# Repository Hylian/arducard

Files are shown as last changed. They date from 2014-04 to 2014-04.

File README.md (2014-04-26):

arducard
========

An open-source Arduino derivative e-paper dev device.

Features
-----

* ATmega32U4 (Same as the Arduino Leonardo)
* USB transceiver
* DS1343 Real-Time Clock
* 128KB FRAM
* LiR2016 Coin-cell Li-Ion battery
* Battery charging over USB
* 2.7" e-Paper display
* 5 edge-mounted interrupt-triggered tactile buttons

Dimensions
----------

80 mm x 45 mm x 5 mm

Applications
------------

* Google Auth Time-OTP 
* Store barcodes for rewards cards, etc.
* Store QR codes
* USB text terminal for Raspberry Pi
* ...

Interested?
-----------

Tweet me at [@inwardshed](https://twitter.com/inwardshed) or e-mail at [edshin95@gmail.com](mailto:edshin95@gmail.com) if you're interested in assembling a PCB/contributing.

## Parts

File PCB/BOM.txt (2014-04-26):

Partlist

Exported from arducard.sch at 4/12/2014 8:20:19 PM

EAGLE Version 6.5.0 Copyright (c) 1988-2013 CadSoft

Assembly variant: 

Part     Value           Device             Package             Library                 Sheet

B2       LIR2016         LIR2016            BK-5067             arducard-coincell       1
C1       100n            C-EUC0603          C0603-ROUND         SmartPrj                1
C2       100n            C-EUC0603          C0603-ROUND         SmartPrj                1
C3       22p             C-EUC0603          C0603-ROUND         SmartPrj                1
C4       22p             C-EUC0603          C0603-ROUND         SmartPrj                1
C5       1uF             C-EUC0603          C0603-ROUND         SmartPrj                1
C6       1uF             C-EUC0603          C0603-ROUND         SmartPrj                1
C7       100nF           C-EUC0603          C0603-ROUND         SmartPrj                1
C8       10u             C-EUC0603          C0603-ROUND         SmartPrj                1
C9       100n            C-EUC0603          C0603-ROUND         SmartPrj                1
C10      4.7 uF          C-EUC0603          C0603-ROUND         SmartPrj                1
C11      10 uF           C-EUC0603          C0603-ROUND         SmartPrj                1
C12      100pF           C-EUC0603          C0603-ROUND         SmartPrj                1
C13      22 pF           C-EUC0603          C0603-ROUND         SmartPrj                1
C14      1uF             C-EUC0603          C0603-ROUND         SmartPrj                1
C15      2.2uF/10V       C-EUC0603          C0603-ROUND         SmartPrj                1
C16      2.2uF/16V       C-EUC0603          C0603-ROUND         SmartPrj                1
C17      2.2uF/16V       C-EUC0603          C0603-ROUND         SmartPrj                1
C18      2.2uF/25V       C-EUC0603          C0603-ROUND         SmartPrj                1
C19      2.2uF/16V       C-EUC0603          C0603-ROUND         SmartPrj                1
C20      2.2uF/25V       C-EUC0603          C0603-ROUND         SmartPrj                1
C21      2.2uF/25V       C-EUC0603          C0603-ROUND         SmartPrj                1
C22      2.2uF/16V       C-EUC0603          C0603-ROUND         SmartPrj                1
C23      2.2uF/16V       C-EUC0603          C0603-ROUND         SmartPrj                1
C24      2.2uF/16V       C-EUC0603          C0603-ROUND         SmartPrj                1
C25      2.2uF/16V       C-EUC0603          C0603-ROUND         SmartPrj                1
C26      1uF/10V         C-EUC0603          C0603-ROUND         SmartPrj                1
C27      2.2uF/25V       C-EUC0603          C0603-ROUND         SmartPrj                1
C28      2.2uF/25V       C-EUC0603          C0603-ROUND         SmartPrj                1
C29      2.2uF/16V       C-EUC0603          C0603-ROUND         SmartPrj                1
C30      2.2uF/16V       C-EUC0603          C0603-ROUND         SmartPrj                1
C31      100nF           C-EUC0603          C0603-ROUND         SmartPrj                1
C32      0.1uF/16V       C-EUC0603          C0603-ROUND         SmartPrj                1
C33      2.2uF/16V       C-EUC0603          C0603-ROUND         SmartPrj                1
D1       BAS40           BAS40              SOT23               diode                   1
D2       BAT54S          BAT54S             SOT23               diode                   1
ICSP     ICSP            PINHD-2X3          2X03                SmartPrj                1
J1       USB MICRO B     MYCON2_USB-MINI-B  CON2_USB_MICRO_B_AT SmartPrj                1
J3       051296-4094     051296-4094        051296-4094         arducard-fpc            1
L2       2.2 uH          INDUCTOR30OHM,1.8A 0603                SparkFun-Passives       1
Q1       BSS84           BSS84              SOT23               transistor-small-signal 1
Q2       BC817-16LT1SMD  BC817-16LT1SMD     SOT23-BEC           transistor-npn          1
Q3       DMG2301U-7      DMG2301U-7         SOT23               transistor-fet          1
Q4       2N7002          2N7002             SOT-23              AWJLEagleLib            1
Q5       BSS84           BSS84              SOT23               transistor-small-signal 1
Q6       2N7002          2N7002             SOT-23              AWJLEagleLib            1
Q7       2N7002          2N7002             SOT-23              AWJLEagleLib            1
Q8       2N7002          2N7002             SOT-23              AWJLEagleLib            1
Q9       BSS84           BSS84              SOT23               transistor-small-signal 1
Q10      DMG2301U-7      DMG2301U-7         SOT23               transistor-fet          1
R1       1M              R-EU_R0603         R0603-ROUND         SmartPrj                1
R2       10k             R-EU_R0603         R0603-ROUND         SmartPrj                1
R3       22R             R-EU_R0603         R0603-ROUND         SmartPrj                1
R4       22R             R-EU_R0603         R0603-ROUND         SmartPrj                1
R5       2k              R-EU_R0603         R0603-ROUND         SmartPrj                1
R6       100k            R-EU_R0603         R0603-ROUND         SmartPrj                1
R7       39k             R-EU_R0603         R0603-ROUND         SmartPrj                1
R8       10k             R-EU_R0603         R0603-ROUND         SmartPrj                1
R9       10k             R-EU_R0603         R0603-ROUND         SmartPrj                1
R10      10k             R-EU_R0603         R0603-ROUND         SmartPrj                1
R11      10k             R-EU_R0603         R0603-ROUND         SmartPrj                1
R12      10k             R-EU_R0603         R0603-ROUND         SmartPrj                1
R13      10k             R-EU_R0603         R0603-ROUND         SmartPrj                1
R14      150             R-EU_R0603         R0603-ROUND         SmartPrj                1
R15      150             R-EU_R0603         R0603-ROUND         SmartPrj                1
R16      150             R-EU_R0603         R0603-ROUND         SmartPrj                1
R17      150             R-EU_R0603         R0603-ROUND         SmartPrj                1
R18      150             R-EU_R0603         R0603-ROUND         SmartPrj                1
R19      10k             R-EU_R0603         R0603-ROUND         SmartPrj                1
R20      18.2k           R-EU_R0603         R0603-ROUND         SmartPrj                1
R23      2k              R-EU_R0603         R0603-ROUND         SmartPrj                1
R24      100k            R-EU_R0603         R0603-ROUND         SmartPrj                1
R25      100k            R-EU_R0603         R0603-ROUND         SmartPrj                1
R26      100k            R-EU_R0603         R0603-ROUND         SmartPrj                1
R27      33k             R-EU_R0603         R0603-ROUND         SmartPrj                1
R28      10k             R-EU_R0603         R0603-ROUND         SmartPrj                1
SW0      EVQ-PUA         EVQ-PUA            SMD-TACT-SWITCH     arducard-switch         1
SW1      EVQ-PUA         EVQ-PUA            SMD-TACT-SWITCH     arducard-switch         1
SW2      EVQ-PUA         EVQ-PUA            SMD-TACT-SWITCH     arducard-switch         1
SW3      EVQ-PUA         EVQ-PUA            SMD-TACT-SWITCH     arducard-switch         1
SW4      EVQ-PUA         EVQ-PUA            SMD-TACT-SWITCH     arducard-switch         1
U1       ATMEGA32U4-XUAU ATMEGA32U4-XUAU    TQFP44-PAD          SmartPrj                1
U2                       MIC5219XX          SOT23-5             v-reg-micrel            1
U3       MB85RS128B-FRAM MB85RS128B-FRAM    SO-08               arducard-fram           1
U4       DS1343          DS1343             TSSOP20             arducard-rtc            1
U5       XC6802A42XMR-G  XC6802A42XMR-G     SOT23-5L            arducard-xc6802         1
Y1       8MHz KX-7       CRYSTAL-3.2-2.5    CRYSTAL-3.2-2.5     SmartPrj                1
Y2       32.768 kHz      SSP-T7-F           SSP-T7-F            arducard-rtc            1
Z1       CG0603MLC-05E   VARISTORCN0603     CT/CN0603           varistor                1
Z2       CG0603MLC-05E   VARISTORCN0603     CT/CN0603           varistor                1

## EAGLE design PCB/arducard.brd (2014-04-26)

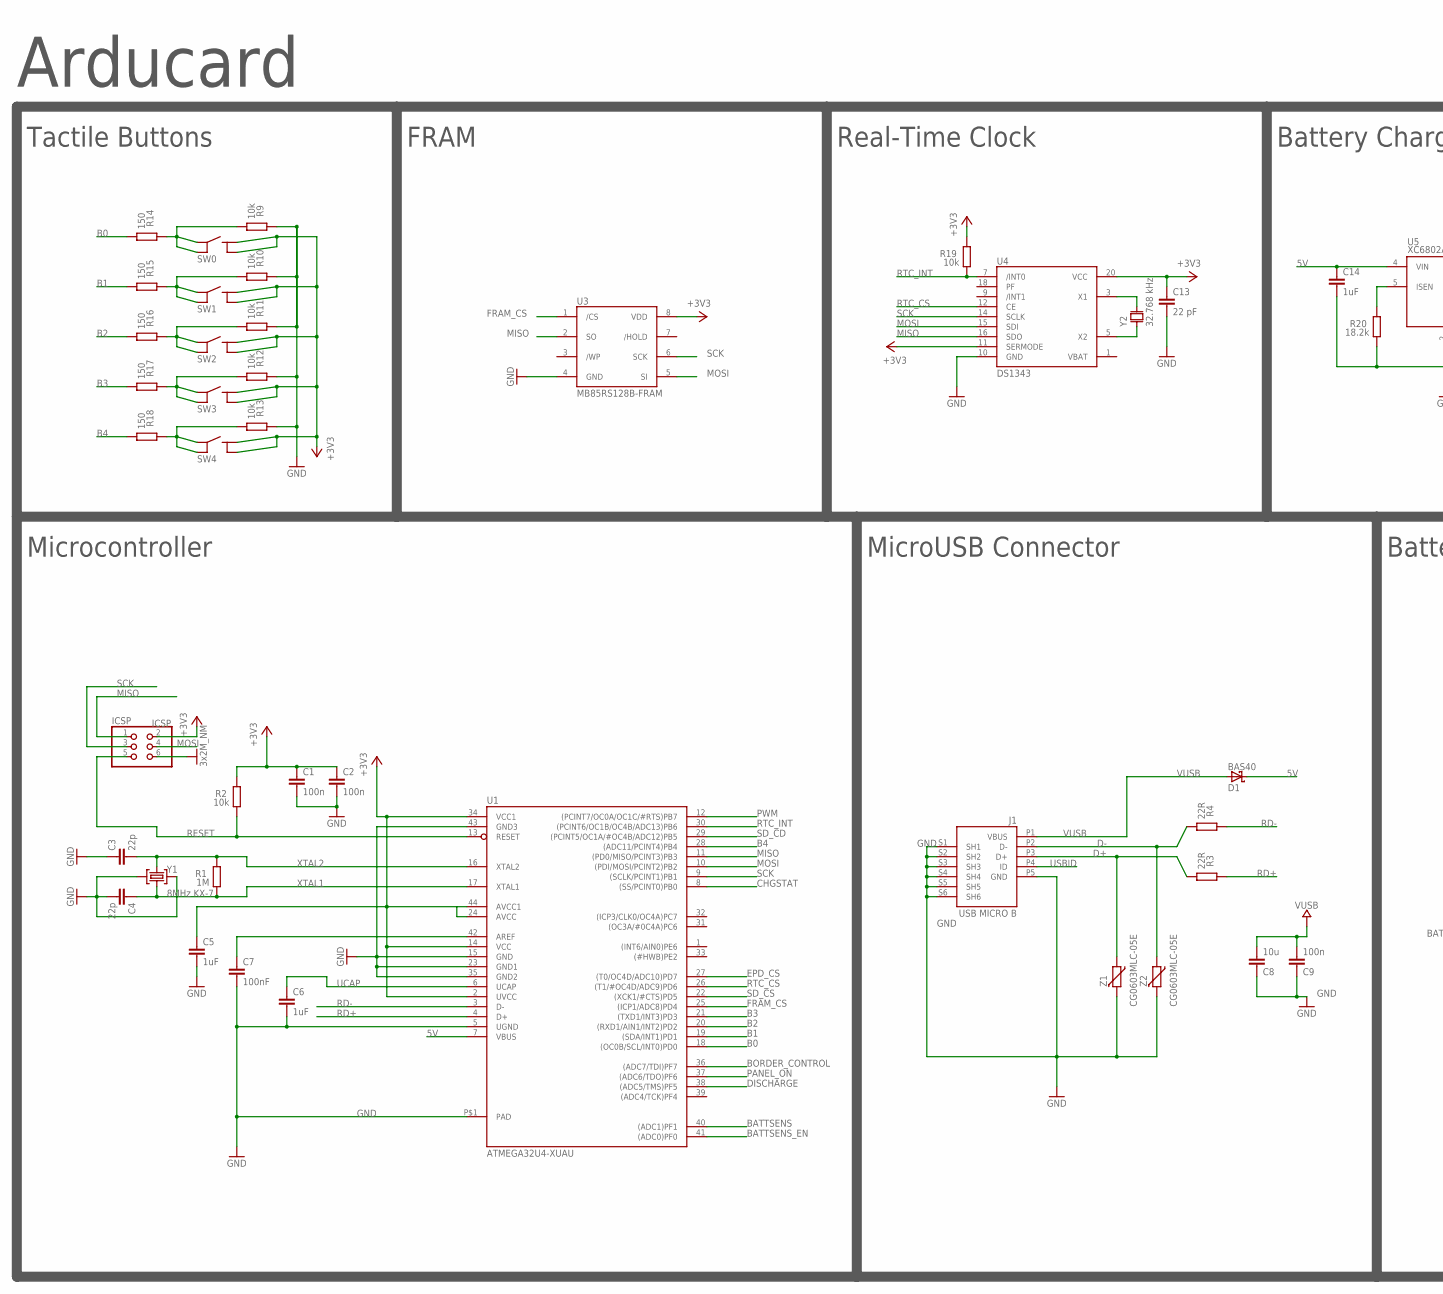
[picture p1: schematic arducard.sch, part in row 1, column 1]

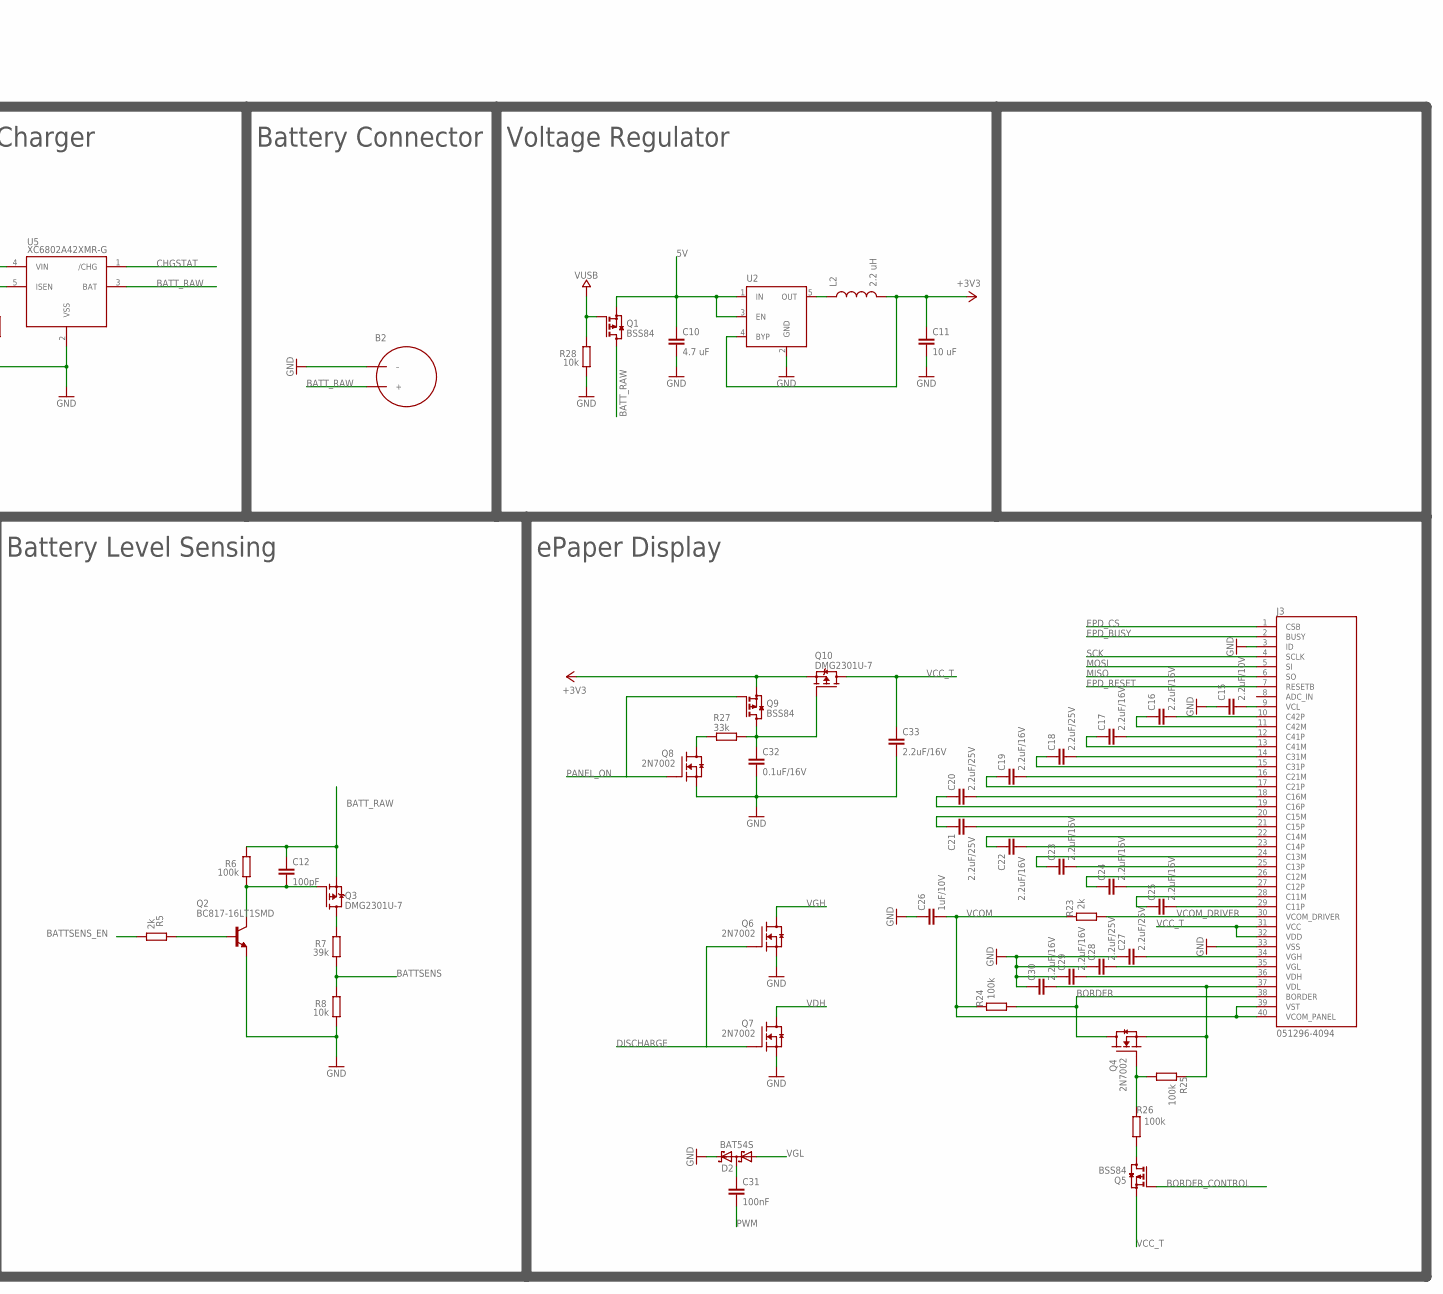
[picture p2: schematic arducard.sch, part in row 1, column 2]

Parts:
B2: LIR2016; BK-5067
C1, C2, C9: 100n; C0603-ROUND
C3, C4: 22p; C0603-ROUND
C5, C6, C14: 1uF; C0603-ROUND
C7, C31: 100nF; C0603-ROUND
C8: 10u; C0603-ROUND
C10: 4.7 uF; C0603-ROUND
C11: 10 uF; C0603-ROUND
C12: 100pF; C0603-ROUND
C13: 22 pF; C0603-ROUND
C15: 2.2uF/10V; C0603-ROUND
C16, C17, C19, C22, C23, C24, C25, C29, C30, C33: 2.2uF/16V; C0603-ROUND
C18, C20, C21, C27, C28: 2.2uF/25V; C0603-ROUND
C26: 1uF/10V; C0603-ROUND
C32: 0.1uF/16V; C0603-ROUND
D1: BAS40; SOT23
D2: BAT54S; SOT23
ICSP: ICSP; 2X03
J1: USB MICRO B; CON2_USB_MICRO_B_AT
J3: 051296-4094
L2: 2.2 uH; 0603
Q1, Q5, Q9: BSS84; SOT23
Q2: BC817-16LT1SMD; SOT23-BEC
Q3, Q10: DMG2301U-7; SOT23
Q4, Q6, Q7, Q8: 2N7002; SOT-23
R1: 1M; R0603-ROUND
R2, R8, R9, R10, R11, R12, R13, R19, R28: 10k; R0603-ROUND
R3, R4: 22R; R0603-ROUND
R5, R23: 2k; R0603-ROUND
R6, R24, R25, R26: 100k; R0603-ROUND
R7: 39k; R0603-ROUND
R14, R15, R16, R17, R18: 150; R0603-ROUND
R20: 18.2k; R0603-ROUND
R27: 33k; R0603-ROUND
SW0, SW1, SW2, SW3, SW4: EVQ-PUA; SMD-TACT-SWITCH
U1: ATMEGA32U4-XUAU; TQFP44-PAD
U2: MIC5219XX; SOT23-5
U3: MB85RS128B-FRAM; SO-08
U4: DS1343; TSSOP20
U5: XC6802A42XMR-G; SOT23-5L
Y1: 8MHz KX-7; CRYSTAL-3.2-2.5
Y2: 32.768 kHz; SSP-T7-F
Z1, Z2: CG0603MLC-05E; CT/CN0603

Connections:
5V: C10.1, C14.1, D1.3 (C), Q1.2 (S), U1.7 (VBUS), U2.1 (IN), U2.3 (EN), U5.4 (VIN)
+3V3: C1.1, C2.1, C5.1, C11.1, C13.1, ICSP.2, L2.2, Q9.2 (S), Q10.2 (S), R2.2, R19.2, SW0.2, SW0.4, SW1.2, SW1.4, SW2.2, SW2.4, SW3.2, SW3.4, SW4.2, SW4.4, U1.2 (UVCC), U1.14 (VCC), U1.24 (AVCC), U1.34 (VCC1), U1.44 (AVCC1), U2.4 (BYP), U3.8 (VDD), U4.11 (SERMODE), U4.20 (VCC)
B0: R14.1, U1.18 ((OC0B/SCL/INT0)PD0)
B1: R15.1, U1.19 ((SDA/INT1)PD1)
B2: R16.1, U1.20 ((RXD1/AIN1/INT2)PD2)
B3: R17.1, U1.21 ((TXD1/INT3)PD3)
B4: R18.1, U1.28 ((ADC11/PCINT4)PB4)
BATTSENS: R7.1, R8.2, U1.40 ((ADC1)PF1)
BATTSENS_EN: R5.1, U1.41 ((ADC0)PF0)
BATT_RAW: B2.POS1 (+), B2.POS2 (+), C12.1, Q1.3 (D), Q3.2 (S), R6.2, U5.3 (BAT)
BORDER: J3.38 (BORDER), Q4.3 (D), R24.2
BORDER_CONTROL: Q5.1 (G), U1.36 ((ADC7/TDI)PF7)
CHGSTAT: U1.8 ((SS/PCINT0)PB0), U5.1 (/CHG)
D+: J1.P3 (D+), R3.1, Z1.1
D-: J1.P2 (D-), R4.1, Z2.1
DISCHARGE: Q6.1 (G), Q7.1 (G), U1.38 ((ADC5/TMS)PF5)
EPD_BUSY: J3.2 (BUSY)
EPD_CS: J3.1 (CSB), U1.27 ((T0/OC4D/ADC10)PD7)
EPD_RESET: J3.7 (RESETB)
FRAM_CS: U1.25 ((ICP1/ADC8)PD4), U3.1 (/CS)
GND: B2.NEG (–), C1.2, C2.2, C3.1, C4.2, C5.2, C6.2, C7.2, C8.1, C9.1, C10.2, C11.2, C13.2, C14.2, C15.1, C26.1, C27.1, C28.1, C29.1, C30.1, C32.2, C33.2, D2.2 (C2), ICSP.6, J1.P5 (GND), J1.S1 (SH1), J1.S2 (SH2), J1.S3 (SH3), J1.S4 (SH4), J1.S5 (SH5), J1.S6 (SH6), J3.3 (ID), J3.33 (VSS), Q2.E, Q6.2 (S), Q7.2 (S), Q8.2 (S), R8.1, R9.2, R10.2, R11.2, R12.2, R13.2, R20.1, R28.1, U1.5 (UGND), U1.15 (GND), U1.23 (GND1), U1.35 (GND2), U1.43 (GND3), U1.P$1 (PAD), U2.2 (GND), U3.4 (GND), U4.10 (GND), U5.2 (VSS), Y1.2 (GND), Y1.4 (GND), Z1.2, Z2.2
MISO: ICSP.1, J3.6 (SO), U1.11 ((PD0/MISO/PCINT3)PB3), U3.2 (SO), U4.16 (SDO)
MOSI: ICSP.4, J3.5 (SI), U1.10 ((PDI/MOSI/PCINT2)PB2), U3.5 (SI), U4.15 (SDI)
unnamed: C15.2, J3.9 (VCL)
unnamed: R10.1, R15.2, SW1.1, SW1.3
unnamed: R9.1, R14.2, SW0.1, SW0.3
unnamed: U4.3 (X1), Y2.P$4
unnamed: R11.1, R16.2, SW2.1, SW2.3
unnamed: R12.1, R17.2, SW3.1, SW3.3
unnamed: L2.1, U2.5 (OUT)
unnamed: R13.1, R18.2, SW4.1, SW4.3
unnamed: C7.1, U1.42 (AREF)
unnamed: C12.2, Q2.C, Q3.1 (G), R6.1
unnamed: C16.2, J3.10 (C42P)
unnamed: Q3.3 (D), R7.2
unnamed: C16.1, J3.11 (C42M)
unnamed: C17.2, J3.12 (C41P)
unnamed: C17.1, J3.13 (C41M)
unnamed: U4.5 (X2), Y2.P$1
unnamed: C18.2, J3.14 (C31M)
unnamed: C18.1, J3.15 (C31P)
unnamed: C19.2, J3.16 (C21M)
unnamed: C19.1, J3.17 (C21P)
unnamed: C20.2, J3.18 (C16M)
unnamed: C20.1, J3.19 (C16P)
unnamed: C21.1, J3.20 (C15M)
unnamed: C21.2, J3.21 (C15P)
unnamed: C22.2, J3.23 (C14P)
unnamed: C22.1, J3.22 (C14M)
unnamed: C23.2, J3.25 (C13P)
unnamed: C23.1, J3.24 (C13M)
unnamed: C24.2, J3.27 (C12P)
unnamed: C24.1, J3.26 (C12M)
unnamed: C25.2, J3.29 (C11P)
unnamed: C25.1, J3.28 (C11M)
unnamed: Q8.3 (D), R27.1
unnamed: R20.2, U5.5 (ISEN)
unnamed: Q5.3 (D), R26.2
unnamed: Q4.1 (G), R25.2, R26.1
unnamed: C31.1, D2.3 (C1A2)
unnamed: C32.1, Q9.3 (D), Q10.1 (G), R27.2
PANEL_ON: Q8.1 (G), Q9.1 (G), U1.37 ((ADC6/TDO)PF6)
PWM: C31.2, U1.12 ((PCINT7/OC0A/OC1C/#RTS)PB7)
Q2: Q2.B, R5.2
RD+: R3.2, U1.4 (D+)
RD-: R4.2, U1.3 (D-)
RESET: ICSP.5, R2.1, U1.13 (RESET)
RTC_CS: U1.26 ((T1/#OC4D/ADC9)PD6), U4.12 (CE)
RTC_INT: R19.1, U1.30 ((PCINT6/OC1B/OC4B/ADC13)PB6), U4.7 (/INT0)
SCK: ICSP.3, J3.4 (SCLK), U1.9 ((SCLK/PCINT1)PB1), U3.6 (SCK), U4.14 (SCLK)
SD_CD: U1.29 ((PCINT5/OC1A/#OC4B/ADC12)PB5)
SD_CS: U1.22 ((XCK1/#CTS)PD5)
UCAP: C6.1, U1.6 (UCAP)
USBID: J1.P4 (ID)
VCC_T: C33.1, J3.31 (VCC), J3.32 (VDD), Q5.2 (S), Q10.3 (D)
VCOM: C26.2, J3.39 (VST), J3.40 (VCOM_PANEL), R23.1, R24.1
VCOM_DRIVER: J3.30 (VCOM_DRIVER), R23.2
VDH: C29.2, J3.36 (VDH), Q7.3 (D)
VDL: C30.2, J3.37 (VDL), Q4.2 (S), R25.1
VGH: C27.2, J3.34 (VGH), Q6.3 (D)
VGL: C28.2, D2.1 (A1), J3.35 (VGL)
VUSB: C8.2, C9.2, D1.1 (A), J1.P1 (VBUS), Q1.1 (G), R28.2
XTAL1: C4.1, R1.1, U1.17 (XTAL1), Y1.1 (C1)
XTAL2: C3.2, R1.2, U1.16 (XTAL2), Y1.3 (C2)

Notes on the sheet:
Voltage Regulator
Battery Connector
Battery Charger
Real-Time Clock
FRAM
Tactile Buttons
Microcontroller
MicroUSB Connector
Battery Level Sensing
ePaper Display
Arducard

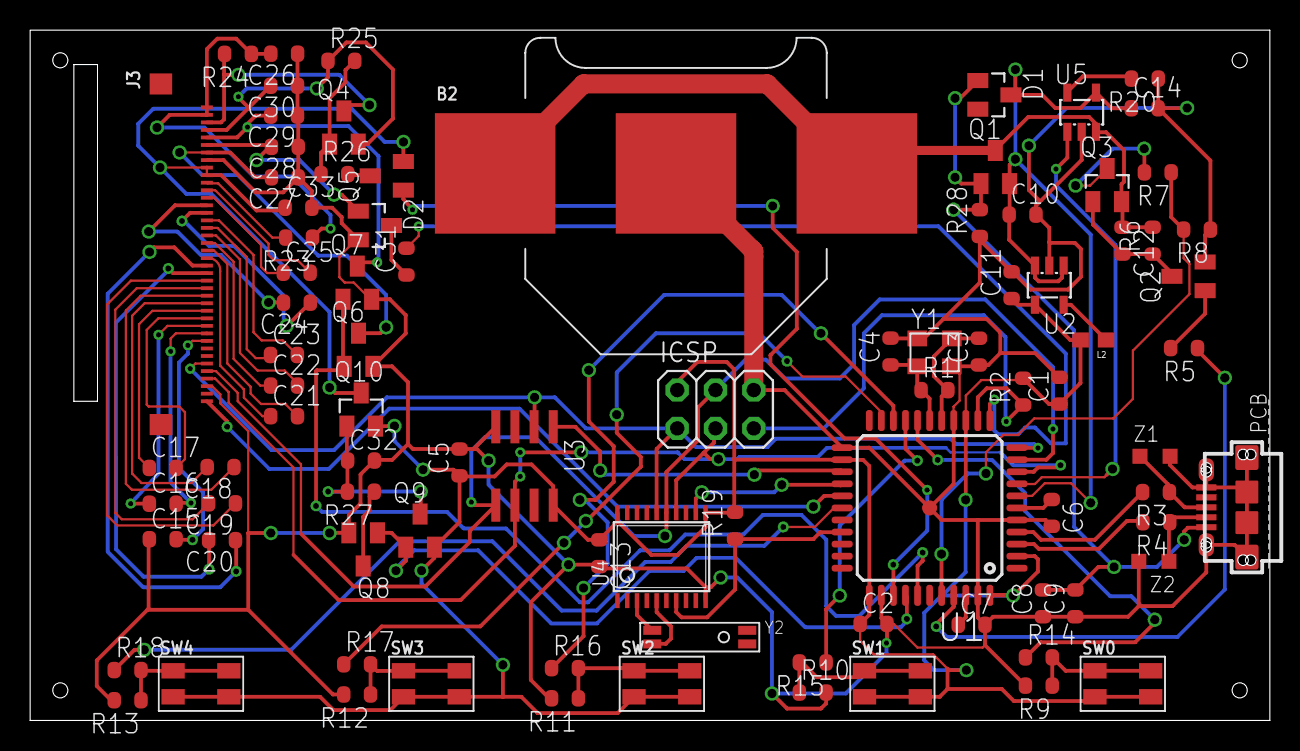
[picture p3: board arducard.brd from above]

Board: 2 copper layers, 82.3 x 45.8 mm, 90 parts (0 on the bottom side), 79 nets.

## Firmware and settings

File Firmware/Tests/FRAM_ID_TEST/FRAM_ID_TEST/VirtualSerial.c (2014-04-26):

/*
             LUFA Library
     Copyright (C) Dean Camera, 2014.

  dean [at] fourwalledcubicle [dot] com
           www.lufa-lib.org
*/

/*
  Copyright 2014  Dean Camera (dean [at] fourwalledcubicle [dot] com)

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
  The author disclaims all warranties with regard to this
  software, including all implied warranties of merchantability
  and fitness.  In no event shall the author be liable for any
  special, indirect or consequential damages or any damages
  whatsoever resulting from loss of use, data or profits, whether
  in an action of contract, negligence or other tortious action,
  arising out of or in connection with the use or performance of
  this software.
*/

/** \file
 *
 *  Main source file for the VirtualSerial demo. This file contains the main tasks of
 *  the demo and is responsible for the initial application hardware configuration.
 */

#include "VirtualSerial.h"
#include <avr/io.h>
#include <util/delay.h>


#define SELECT_FRAM PORTD &= ~(0x08)
#define DESELECT_FRAM PORTD |= 0x08

/** LUFA CDC Class driver interface configuration and state information. This structure is
 *  passed to all CDC Class driver functions, so that multiple instances of the same class
 *  within a device can be differentiated from one another.
 */
USB_ClassInfo_CDC_Device_t VirtualSerial_CDC_Interface =
	{
		.Config =
			{
				.ControlInterfaceNumber   = INTERFACE_ID_CDC_CCI,
				.DataINEndpoint           =
					{
						.Address          = CDC_TX_EPADDR,
						.Size             = CDC_TXRX_EPSIZE,
						.Banks            = 1,
					},
				.DataOUTEndpoint =
					{
						.Address          = CDC_RX_EPADDR,
						.Size             = CDC_TXRX_EPSIZE,
						.Banks            = 1,
					},
				.NotificationEndpoint =
					{
						.Address          = CDC_NOTIFICATION_EPADDR,
						.Size             = CDC_NOTIFICATION_EPSIZE,
						.Banks            = 1,
					},
			},
	};

/** Standard file stream for the CDC interface when set up, so that the virtual CDC COM port can be
 *  used like any regular character stream in the C APIs.
 */
static FILE USBSerialStream;


/** Main program entry point. This routine contains the overall program flow, including initial
 *  setup of all components and the main program loop.
 */
int main(void)
{
	SetupHardware();

	/* Create a regular character stream for the interface so that it can be used with the stdio.h functions */
	CDC_Device_CreateStream(&VirtualSerial_CDC_Interface, &USBSerialStream);

	GlobalInterruptEnable();
	

	int one, two, three, four;
	char* reportString = NULL;
		
	DDRD = 0x08;
	DDRB = 0x06;
		
	SPCR = SPE | MSTR;
		
	SPSR;
	SPDR;
		
	SELECT_FRAM;
	_delay_us(100);
	while(1)
	{
		SPDR = 0x9F;
		while(!(SPSR & SPIF));
		SPDR = 0x00;
		while(!(SPSR & SPIF));
		one = SPDR;
		SPDR = 0x00;
		while(!(SPSR & SPIF));
		two = SPDR;
		SPDR = 0x00;
		while(!(SPSR & SPIF));
		three = SPDR;
		SPDR = 0x00;
		while(!(SPSR & SPIF));
		four = SPDR;		
			
		if((one == 0x04) & (two == 0x7F) & (three == 0x04) & (four = 0x09))
			reportString = "ID Check pass!";
		else
			reportString = "ID Check fail!";
			
			
		fputs(reportString, &USBSerialStream);

		/* Must throw away unused bytes from the host, or it will lock up while waiting for the device */
		CDC_Device_ReceiveByte(&VirtualSerial_CDC_Interface);

		CDC_Device_USBTask(&VirtualSerial_CDC_Interface);
		USB_USBTask();
	}
}

/** Configures the board hardware and chip peripherals for the demo's functionality. */
void SetupHardware(void)
{
	/* Disable watchdog if enabled by bootloader/fuses */
	MCUSR &= ~(1 << WDRF);
	wdt_disable();

	/* Disable clock division */
	clock_prescale_set(clock_div_1);

	/* Hardware Initialization */
	USB_Init();
}


/** Event handler for the library USB Connection event. */
void EVENT_USB_Device_Connect(void)
{
}

/** Event handler for the library USB Disconnection event. */
void EVENT_USB_Device_Disconnect(void)
{
}

/** Event handler for the library USB Configuration Changed event. */
void EVENT_USB_Device_ConfigurationChanged(void)
{
	bool ConfigSuccess = true;

	ConfigSuccess &= CDC_Device_ConfigureEndpoints(&VirtualSerial_CDC_Interface);

}

/** Event handler for the library USB Control Request reception event. */
void EVENT_USB_Device_ControlRequest(void)
{
	CDC_Device_ProcessControlRequest(&VirtualSerial_CDC_Interface);
}

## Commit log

2014-01-02 Very preliminary PCB design; everything except display circuit
    [arducard.sch]
2014-02-23 Added DS3234 Real Time Clock
    [arducard.sch]
2014-02-24 Added display ZIF connector and control circuit
    [arducard.sch]
2014-02-24 Added voltage ratings to display control circuit
    [arducard.sch]
2014-02-25 Added EPD panel on control
    [arducard.sch]
2014-02-25 Changed battery level sensing transistor
    [arducard.sch]
2014-03-02 Added extra button
2014-03-09 added battery connector
    [arducard.sch]
2014-03-10 changed SRAM to FRAM
    [arducard.sch]
2014-03-10 added 5th button
    [arducard.brd, arducard.sch]
2014-03-10 removed reset switch
    [arducard.sch]
2014-03-11 added coin cell battery
    [arducard.sch]
2014-03-12 changed RTC to DS1343
    [arducard.brd, arducard.sch]
2014-03-12 added bypass cap to vreg input
    [arducard.sch]
2014-03-12 organized schematic layout
    [arducard.sch]
2014-03-13 added switch between Vusb and battery
    [arducard.sch]
2014-03-13 fixed up libraries
    [arducard.sch]
2014-03-14 initial board layout
    [arducard.brd, arducard.sch]
2014-03-14 removed microsd
    [arducard.brd, arducard.sch]
2014-03-29 fixed VUSB diode
    [arducard.brd, arducard.sch]
2014-03-29 removed flat cell battery connector
    [arducard.brd, arducard.sch]
2014-04-12 initial routing for dorkbot
    [arducard.brd, arducard.sch]
2014-04-13 added gerber for stencil and fixed missing trace
    [arducard.brd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]
2014-04-15 added button description
2014-04-26 renamed a part
    [arducard.brd, arducard.sch]

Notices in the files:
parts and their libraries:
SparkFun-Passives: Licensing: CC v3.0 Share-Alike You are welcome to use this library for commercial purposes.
